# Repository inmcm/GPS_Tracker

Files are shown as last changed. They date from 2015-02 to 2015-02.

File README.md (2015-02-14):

# GPS_Tracker
My own little spin on a GPS tracker/logger device

## Main Components
- Controller: [Teensy 3.x]
- GPS: Adafruit [Ultimate GPS Breakout]
- Display: Adafruit [128x32 I2C OLED Display]
- Accelerometer: [ADXL345]
- LiPo Charger: [MCP73831]
- Regulator: [MIC5219]
- SD Card Socket
- Two User Buttons
- On/Off Switch
- JST Connector for LiPo Battery
- Designed to Fit inside an [Otterbox 1000 Watertight Case]

Software remains a work in progress

### Bare PCB
bare_board

### Populated:
populated_board 

[Teensy 3.x]:https://www.pjrc.com/store/teensy31.html
[Ultimate GPS Breakout]:http://www.adafruit.com/product/746
[128x32 I2C OLED Display]:http://www.adafruit.com/product/931
[ADXL345]:https://www.sparkfun.com/products/9045
[MCP73831]:http://www.microchip.com/wwwproducts/Devices.aspx?dDocName=en024903
[MIC5219]:http://micrel.com/products/power-management-ics/ldos/single-ldos/article/85.html
[Otterbox 1000 Watertight Case]:http://www.amazon.com/OtterBox-1000-Series-Waterproof-Case/dp/B000F1ULU8

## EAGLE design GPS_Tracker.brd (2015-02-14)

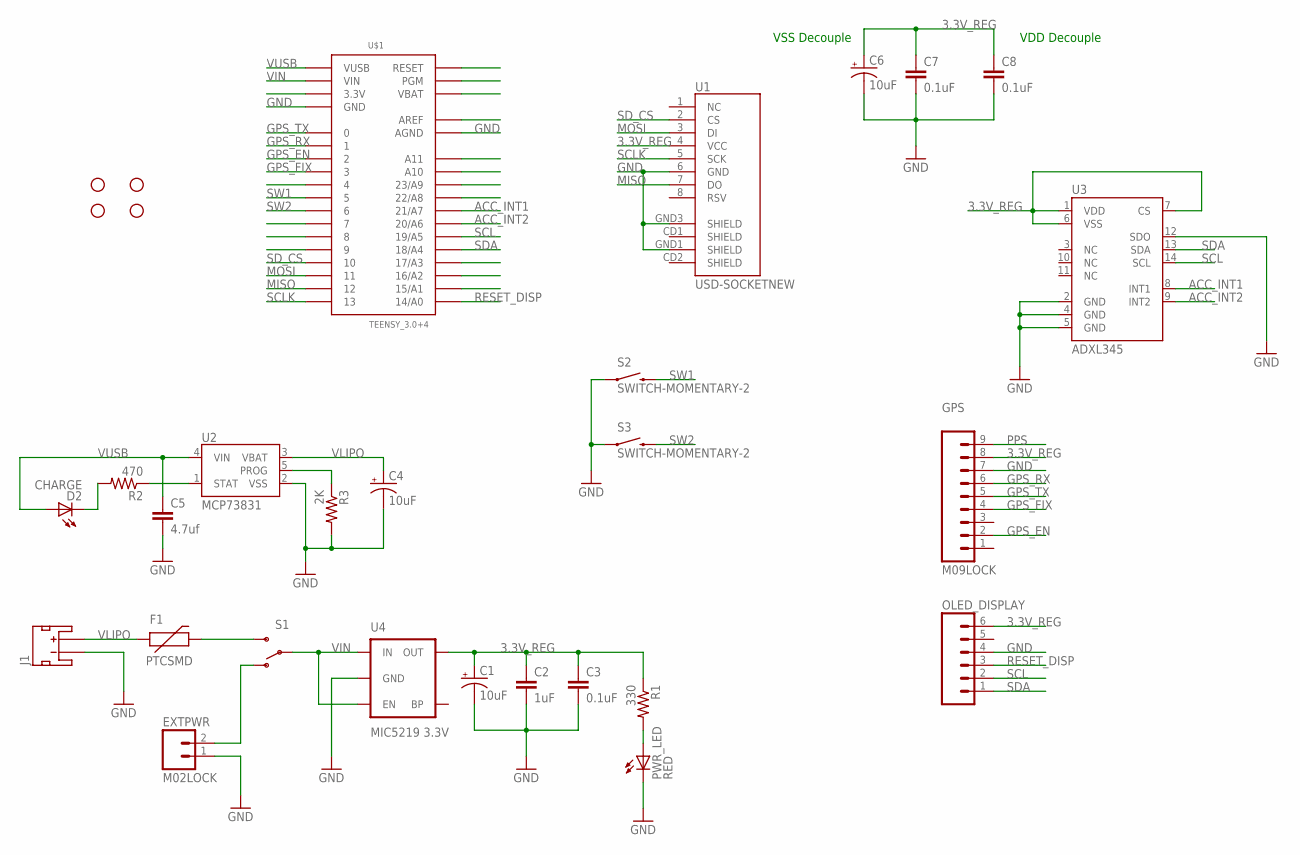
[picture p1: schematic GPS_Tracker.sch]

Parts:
C1, C4, C6: 10uF; EIA3216
C2: 1uF; 0402-CAP
C3, C7, C8: 0.1uF; 0402-CAP
C5: 4.7uf; 0402-CAP
D2: CHARGE; LED-0603
EXTPWR: M02LOCK; 1X02_LOCK
F1: PTCSMD; PTC-1206
GPS: M09LOCK; 1X09_LOCK
J1: JST_2MM_MALE; JST-2-SMD
OLED_DISPLAY: M06LOCK; 1X06_LOCK
PWR_LED: RED; LED-0603
R1: 330; 0402-RES
R2: 470; 0402-RES
R3: 2K; 0402-RES
S1: SWITCH-SPDTSMD; AYZ0202
S2, S3: SWITCH-MOMENTARY-2; TACTILE_SWITCH_TALL
STANDOFF1, STANDOFF2, STANDOFF3, STANDOFF4: STAND-OFF
U1: USD-SOCKETNEW; MICRO-SD-SOCKET-PP
U2: MCP73831; SOT23-5
U3: ADXL345; LGA14
U4: MIC5219 3.3V; SOT23-5
U$1: TEENSY_3.0+4

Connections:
3.3V_REG: C1.A (+), C2.1, C3.1, C6.A (+), C7.1, C8.1, GPS.8, OLED_DISPLAY.6, R1.1, U1.4 (VCC), U3.1 (VDD), U3.6 (VSS), U3.7 (CS), U4.5 (OUT)
ACC_INT1: U3.8 (INT1), U$1.21/A7
ACC_INT2: U3.9 (INT2), U$1.20/A6
GND: C1.C (-), C2.2, C3.2, C4.C (-), C5.2, C6.C (-), C7.2, C8.2, EXTPWR.1, GPS.7, J1.1 (-), OLED_DISPLAY.4, PWR_LED.C, R3.2, S2.A2 (1), S3.A2 (1), U1.6 (GND), U1.GND1 (SHIELD), U1.GND3 (SHIELD), U2.2 (VSS), U3.2 (GND), U3.4 (GND), U3.5 (GND), U3.12 (SDO), U4.2 (GND), U$1.AGND, U$1.GND, U$1.GND1 (GND)
GPS_EN: GPS.2, U$1.2
GPS_FIX: GPS.4, U$1.3
GPS_RX: GPS.6, U$1.1
GPS_TX: GPS.5, U$1.0
MISO: U1.7 (DO), U$1.12
MOSI: U1.3 (DI), U$1.11
unnamed: D2.C, R2.2
unnamed: F1.2, S1.3 (S)
unnamed: EXTPWR.2, S1.1 (O)
unnamed: U$1.3.3V, U$1.3.3V1 (3.3V)
unnamed: PWR_LED.A, R1.2
unnamed: R2.1, U2.1 (STAT)
unnamed: R3.1, U2.5 (PROG)
PPS: GPS.9
RESET_DISP: OLED_DISPLAY.3, U$1.14/A0
SCL: OLED_DISPLAY.2, U3.14 (SCL), U$1.19/A5
SCLK: U1.5 (SCK), U$1.13
SDA: OLED_DISPLAY.1, U3.13 (SDA), U$1.18/A4
SD_CS: U1.2 (CS), U$1.10
SW1: S2.B2 (2), U$1.5
SW2: S3.B2 (2), U$1.6
VIN: S1.2, U4.1 (IN), U4.3 (EN), U$1.VIN
VLIPO: C4.A (+), F1.1, J1.2 (+), U2.3 (VBAT)
VUSB: C5.1, D2.A, U2.4 (VIN), U$1.VUSB

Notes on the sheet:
VSS Decouple
VDD Decouple

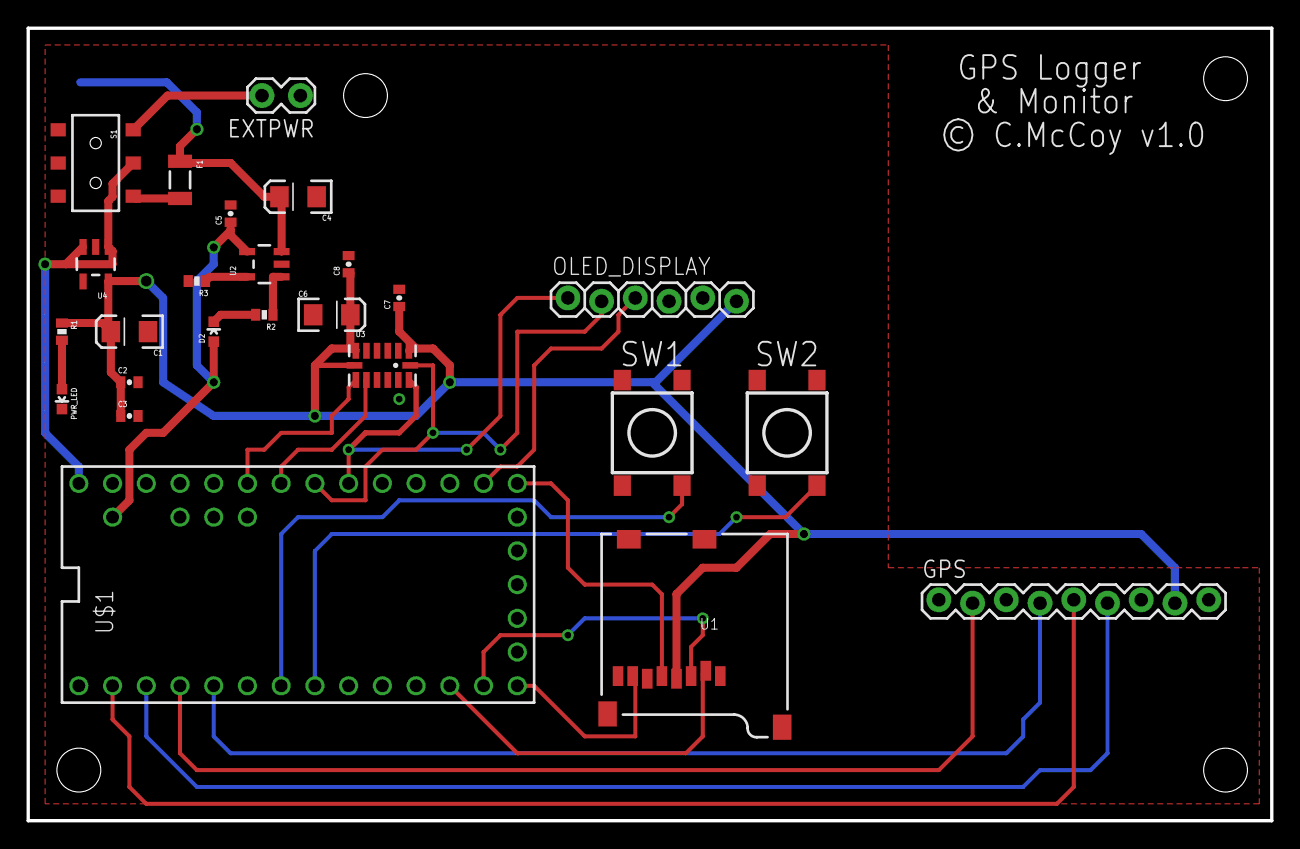
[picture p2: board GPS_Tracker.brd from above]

Board: 2 copper layers, 93.7 x 59.7 mm, 30 parts (1 on the bottom side), 27 nets.

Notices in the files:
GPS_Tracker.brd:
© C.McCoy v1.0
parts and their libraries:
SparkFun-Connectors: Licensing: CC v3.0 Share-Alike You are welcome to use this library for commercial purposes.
